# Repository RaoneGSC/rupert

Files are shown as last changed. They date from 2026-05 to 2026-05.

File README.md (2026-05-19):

# Rupert

<p align="center">
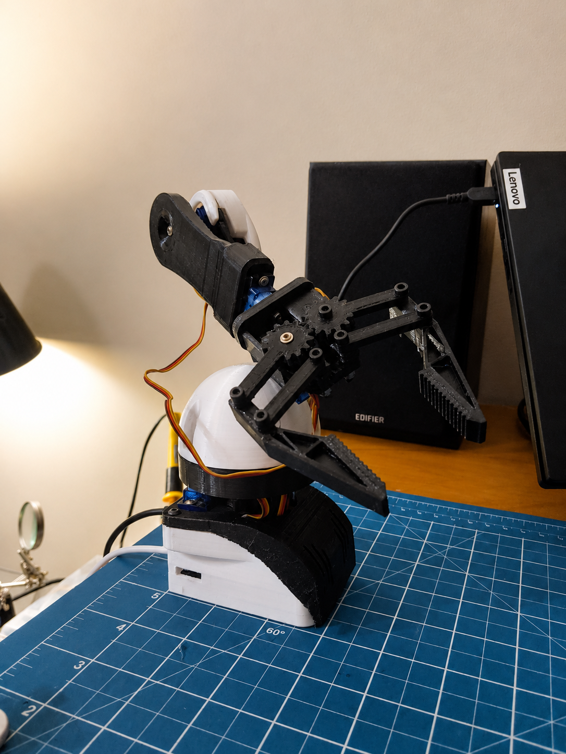
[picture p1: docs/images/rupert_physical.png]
Rupert robotic arm
  
</p>

> **Work in progress.** Rupert is an actively developed platform — control models, simulation, and hardware are continuously being improved. Expect rough edges.

Rupert is a 5-DOF robotic arm built from 3D-printed parts and off-the-shelf components, designed as a low-cost Physical AI testbed. It is the first robot of the [AxisMov](https://github.com/RaoneGSC/axismov) platform.

The main interest of the project is the **sim-to-real pipeline**: training or controlling the robot in simulation (NVIDIA Isaac Sim) and transferring that directly to the physical hardware via serial communication.

---

## Architecture

Rupert is split into two layers:

- **Brain** (`src/brain/`) — runs on the PC, handles simulation, AI, and high-level control
- **Firmware** (`firmware/`) — runs on the Raspberry Pi Pico 2, drives the servos directly

```
PC (Brain)  ──── USB Serial (230400 baud) ────  Pico 2 (Firmware)  ──── PWM ────  Servos
```

<p align="center">
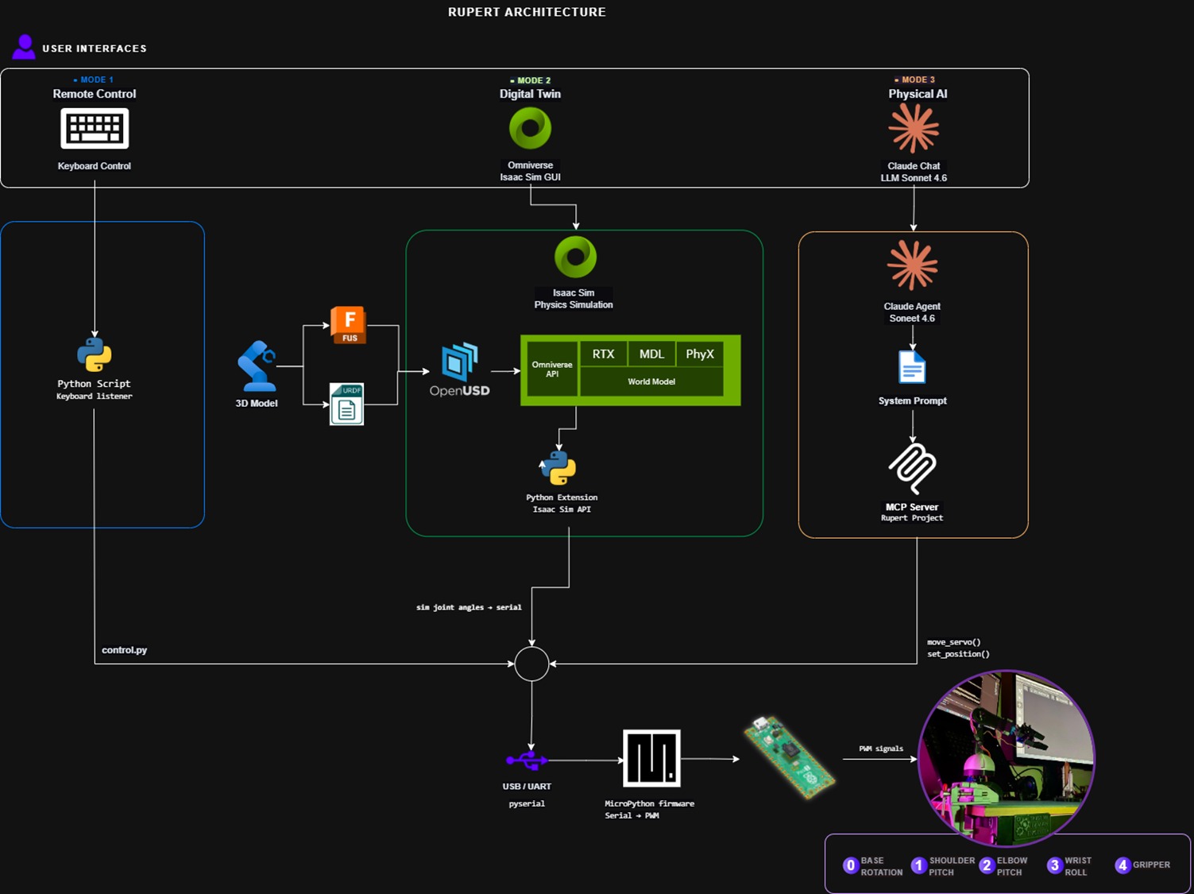
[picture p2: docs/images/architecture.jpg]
Rupert Architecture Diagram
  
</p>

---

## Firmware — Peripheral Nervous System

`firmware/peripheral_system.py` is the MicroPython script that runs on the **Raspberry Pi Pico 2**. Flash it using [Thonny](https://thonny.org/) or `mpremote`.

It listens on USB serial for commands in the format:

```
angle0,angle1,angle2,angle3,angle4\n
```

And responds with:

```
OK,angle0,angle1,angle2,angle3,angle4
```

Or `ERR,FORMAT` / `ERR,<message>` on failure. On startup it prints `READY`.

| Pin | Joint | Servo | Notes |
|---|---|---|---|
| 15 | Base | SG92R | carbon fiber gears — handles higher torque |
| 14 | Shoulder | MG90S | metal gear — highest load area |
| 13 | Elbow | SG92R | carbon fiber gears — handles higher torque |
| 12 | Wrist | SG90 | opens/closes gripper |
| 19 | Gripper | SG90 | wrist rotation |

---

## Kinematics

Rupert is a **5-DOF serial manipulator** with the following joint chain:

| Joint | Index | Motion | Range | Servo |
|---|---|---|---|---|
| Base | 0 | Rotation (yaw) | 5° – 175° | SG92R |
| Shoulder | 1 | Pitch | 5° – 160° | MG90S |
| Elbow | 2 | Pitch | 5° – 175° | SG92R |
| Wrist | 3 | Roll | 0° – 180° | SG90 |
| Gripper | 4 | Open / Close | 0° – 180° | SG90 |

**Kinematic chain:**

```
World → Base (yaw) → Shoulder (pitch) → Elbow (pitch) → Wrist (roll) → Gripper (end-effector)
```

- **Base** rotates the entire arm horizontally around the Z axis (yaw)
- **Shoulder + Elbow** form a planar 2-DOF arm in the vertical plane, controlling reach and height via two pitch joints
- **Wrist** rolls the gripper assembly around the forearm axis, allowing orientation of the end-effector
- **Gripper** is a parallel jaw mechanism actuated by a single servo

The arm operates in a **polar coordinate workspace** — the base angle sets the azimuth, while shoulder and elbow angles define the position in the vertical plane. No inverse kinematics solver is currently implemented; control is done by direct joint angle commands.

---

## Brain Modules

Rupert has multiple control interfaces, each in `src/brain/`:

| File | Description |
|---|---|
| `IsaacRupertBrain.py` | **Main sim-to-real bridge** — reads joint positions from Isaac Sim and streams them to the Pico via serial |
| `IsaacBridgeScript.py` | **Isaac Sim TCP bridge** — paste into Isaac Script Editor; opens a socket on port 9877 so the MCP can control the simulation thread-safely |
| `RupertBrainV3.py` | Keyboard-based direct control of the physical robot |
| `RupertBrainPyBulletV2.py` | PyBullet simulation + serial bridge ⚠️ partial assembly (2-DOF only) |
| `RupertBrainPyBulletV1.py` | First PyBullet prototype ⚠️ partial assembly |
| `RupertPhysicalAI.py` | Natural language control via LangChain + Groq |

> ⚠️ The PyBullet scripts and RL training environment (`src/training/`) model a **partial, 2-DOF version** of Rupert, not the full 5-DOF assembly. Full-assembly RL training is on the roadmap.

---

## MCP Servers

Rupert exposes three [MCP](https://modelcontextprotocol.io/) servers that let Claude Desktop control the robot directly:

| File | Server name | Description |
|---|---|---|
| `src/mcp/RupertMCP.py` | `rupert` | Serial servo control — `move_servo`, `move_sequence`, `center_all`, `current_position` |
| `src/mcp/RupertVisionMCP.py` | `rupert-vision` | Webcam computer vision — captures frames Claude can see, monitors motion, detects Rupert position via blue mat anchor |
| `src/mcp/IsaacUSDMCP.py` | `isaac-usd` | Isaac Sim control — connects to `IsaacBridgeScript.py` running inside Isaac, exposes scene inspection and drive control |

### Claude Code slash commands

Three project-scoped commands live in `.claude/commands/`:

| Command | Description |
|---|---|
| `/rupert-mover <text>` | Interprets a natural-language movement command and executes it via the `rupert` MCP |
| `/rupert-visao [goal]` | Full vision-action loop: starts webcam, moves arm, waits for motion to stop, checks result visually, fine-tunes |
| `/rupert-calibrar` | Runs each servo through its full range with camera feedback, reports OK / problem per joint |

---

## Sim-to-Real with NVIDIA Isaac Sim

The most developed pipeline uses **Isaac Sim** as the simulation environment. The robot is controlled in simulation and commands are streamed to the physical hardware in real time.

**Requirements:** [NVIDIA Isaac Sim](https://developer.nvidia.com/isaac/sim) (6.0+)

### Step 1 — Open the scene

Launch Isaac Sim, go to **File → Open**, navigate to the `assets/usd/` folder and open `IsaacRupert.usd`.

<p align="center">
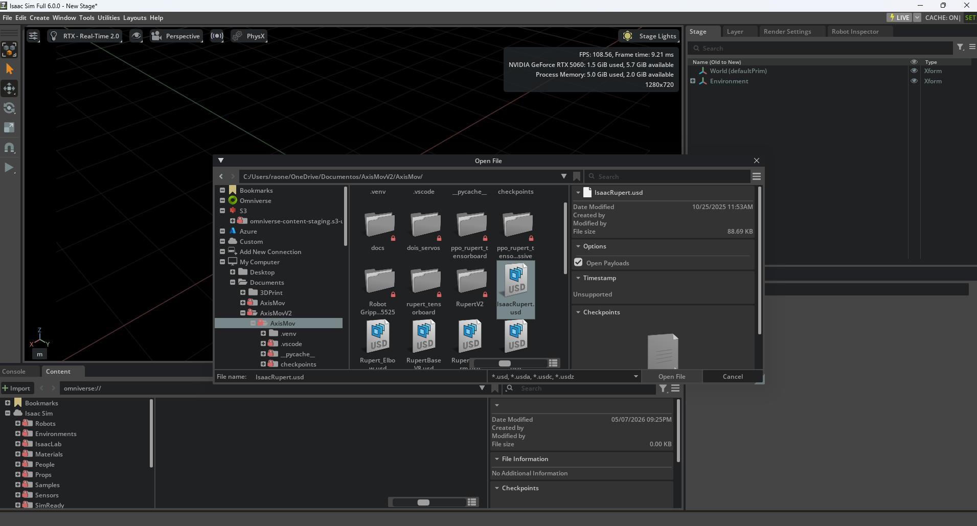
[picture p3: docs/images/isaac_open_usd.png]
Opening IsaacRupert.usd in Isaac Sim
  
</p>

### Step 2 — Flash the firmware

Flash `firmware/pico_servo_protected.py` to the Raspberry Pi Pico 2 using Thonny or `mpremote`. Connect the Pico via USB and confirm the COM port in `IsaacRupertBrain.py`.

### Step 3 — Run the brain script

Once the scene loads you should see Rupert in the viewport with all joints visible in the Physics Inspector.

<p align="center">
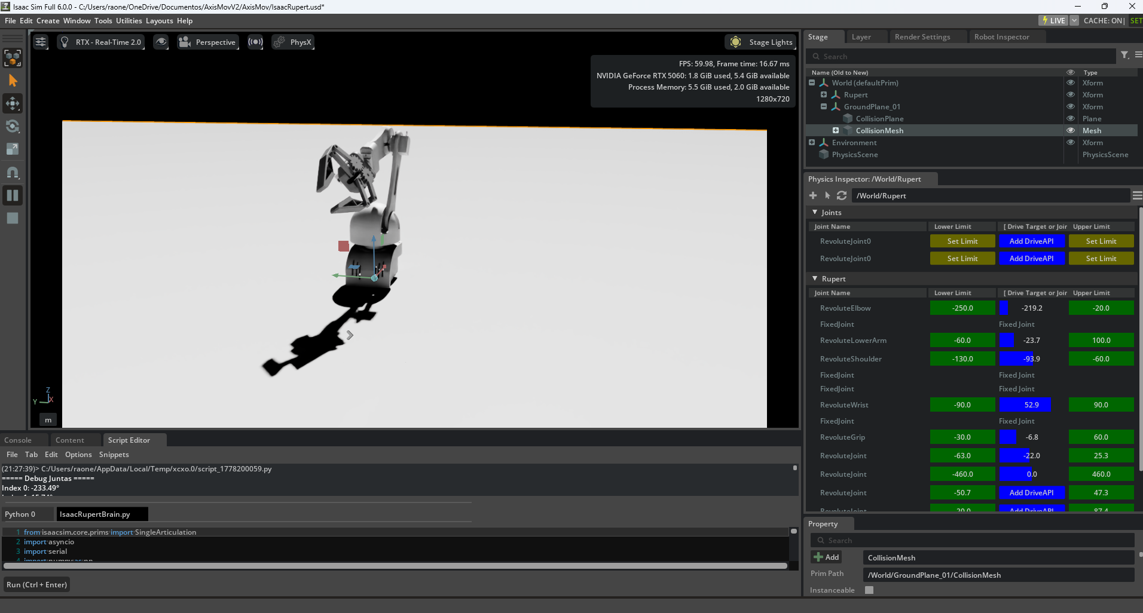
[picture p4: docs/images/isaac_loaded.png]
Rupert loaded in Isaac Sim with joints inspector
  
</p>

Open the **Script Editor** (bottom panel), load `src/brain/IsaacRupertBrain.py` and hit **Run (Ctrl+Enter)**.

The script will:
1. Connect to the Pico via serial (`COM4`, 230400 baud)
2. Start a smooth ramp from 90° to the current simulation position
3. Stream joint angles to the robot at 50Hz

### Step 4 (optional) — Enable Claude control via MCP

To let Claude Desktop control the simulation directly, also run `src/brain/IsaacBridgeScript.py` in the Script Editor. It opens a TCP socket on `localhost:9877` and exposes a thread-safe command queue so the `isaac-usd` MCP can inspect the scene and set drive targets without touching Isaac's USD APIs from the wrong thread.

Available bridge commands: `resumo`, `listar_prims`, `inspecionar`, `obter_juntas`, `buscar_prims`, `definir_drive`, `resetar_drives`, `articulacoes`.

---

## Computer Vision

Rupert uses a low-cost USB webcam as a visual sensor. Two components handle this:

- **`src/mcp/RupertVisionMCP.py`** — MCP server that returns `ImageContent` frames so Claude can see the robot directly. Supports continuous background monitoring, motion detection (frame-diff), and position detection.
- **`scripts/teste_visao_rupert.py`** — Standalone real-time test window (OpenCV). Run this to tune detection before using the MCP. Keyboard shortcuts: `O`=YOLO, `A`=ArUco, `M`=motion mask, `C`=debug masks, `S`=screenshot, `Q`=quit.

### Detection strategy

The robot sits on a **blue cutting mat** which acts as a position anchor:

1. Detect the blue-green mat via HSV segmentation (`H 78–115`)
2. Project the robot bounding-box above the mat
3. Confirm with SG90 servo blobs in the ROI (`H 95–140`)

If detection fails, use `calibrar_deteccao()` via the MCP (or press `C` in the test script) to see the HSV masks, then adjust thresholds with `ajustar_hsv_tapete()` at runtime.

---

## Hardware

Rupert is fully 3D-printable. All parts use **M3 screws**. STL and USD files are in `assets/`.

| Component | Details |
|---|---|
| Microcontroller | Raspberry Pi Pico 2 |
| Motor driver | [Kitronik Simply Robotics Motor Driver Board for Raspberry Pi Pico](https://kitronik.co.uk/products/5348-kitronik-simply-robotics-for-raspberry-pi-pico) |
| Base servo (pin 15) | SG92R — carbon fiber gears |
| Shoulder servo (pin 14) | MG90S — metal gear, highest load area |
| Elbow servo (pin 13) | SG92R — carbon fiber gears |
| Wrist servo (pin 12) | SG90 |
| Gripper servo (pin 19) | SG90 |
| Communication | USB Serial, 230400 baud |
| Fasteners | M3 screws |

---

## Known Issues

Rupert is a work in progress. These are the known limitations currently being addressed:

### Physical

- **Shoulder / Elbow torque** — Even with MG996R servos, the arm length generates more torque than the servos can handle. Movements in these joints are unreliable under load. Planned fix: shorten arm and forearm to reduce required torque.

- **Gripper grip strength** — The current gripper design does not hold objects reliably. For testing, use very lightweight objects (paper, foam). A redesigned gripper with better mechanical advantage is planned.

### Software / Simulation

- **Isaac Sim gripper joints** — The gripper joint connections in `IsaacRupert.usd` have structural issues that can crash the simulation depending on the movement. Needs a clean USD rebuild of the gripper assembly.

- **Ground constraint artifact** — The base is fixed to the ground plane to prevent tipping, which creates unnatural behavior in some poses. A proper base mass/inertia model is the correct fix.

- **PyBullet / RL is 2-DOF only** — The training environment and PyBullet scripts model a simplified 2-joint version of Rupert. Full 5-DOF RL environment is planned.

---

## Roadmap

- [x] **Isaac Sim MCP** — `IsaacUSDMCP.py` + `IsaacBridgeScript.py`: Claude can inspect the scene, read joints, and set drive targets directly from Claude Desktop
- [x] **Computer vision module** — `RupertVisionMCP.py`: webcam integration with blue-mat anchor detection, motion sensing, and `ImageContent` frames Claude can see natively; `scripts/teste_visao_rupert.py` for threshold tuning
- [ ] **Full 5-DOF RL environment** — Extend the Gymnasium environment to the complete arm assembly
- [ ] **Shorter arm/forearm** — Redesign to reduce torque on shoulder and elbow joints
- [ ] **Gripper redesign** — Better mechanical advantage for reliable grasping

---

## Setup

```bash
git clone https://github.com/RaoneGSC/rupert.git
cd rupert
pip install -r requirements.txt
cp .env.example .env   # add your API keys if using RupertPhysicalAI or Autogen
```

Flash the firmware to the Pico separately via Thonny or `mpremote copy firmware/peripheral_system.py :main.py`.

---

## License

MIT

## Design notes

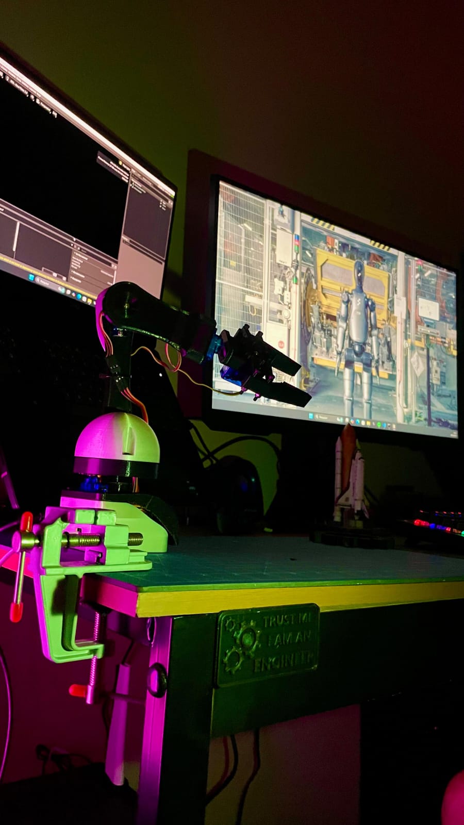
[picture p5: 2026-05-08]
docs/images/rupert_physical.jpg

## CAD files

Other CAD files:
assets/meshes/RupertHand6.stl
assets/meshes/RupertGrip2.stl
assets/meshes/RupertLowerArmV2.stl
assets/meshes/RupertHandTHEONE.stl
assets/meshes/Connector.stl
assets/meshes/RuportGrip1.stl
assets/meshes/RupertHand3.stl
assets/meshes/RupertHand4.stl
assets/meshes/RupertHand2.3.stl
assets/meshes/RupertHand2.stl
assets/meshes/RupertElbow.stl
assets/meshes/RupertHand2.1.stl
assets/meshes/RupertHand1.2.stl
assets/meshes/SG92R.stl
assets/meshes/RupertHand1.stl
assets/meshes/RupertHand7.stl
assets/meshes/RupertBaseV8.stl
assets/meshes/RupertShoulderV6.stl
assets/meshes/RupertForearm.stl
assets/meshes/RupertHand5.stl
assets/meshes/Rupert_Elbow.stl
assets/meshes/vader_saber.stl

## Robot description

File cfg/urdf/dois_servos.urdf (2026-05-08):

<?xml version="1.0"?>
<robot name="dois_servos">

  <!-- Servo Motor 1 (fixado na mesa) -->
  <link name="base_servo1">
    <visual>
      <geometry>
        <box size="0.032 0.012 0.026"/> <!-- Tamanho do servo motor 1 -->
      </geometry>
      <material name="gray"/>
    </visual>
    <collision>
      <geometry>
        <box size="0.032 0.012 0.026"/> <!-- Colisão do servo motor 1 -->
      </geometry>
    </collision>
    <inertial>
      <mass value="0.1"/> <!-- Massa padrão do servo motor 1 -->
      <inertia ix="0.0001" iy="0.0001" iz="0.0001"/> <!-- Inércia padrão -->
    </inertial>
  </link>

  <!-- Servo Motor 2 (girando com o primeiro) -->
  <link name="base_servo2">
    <visual>
      <geometry>
        <box size="0.032 0.012 0.026"/> <!-- Tamanho do servo motor 2 -->
      </geometry>
      <material name="blue"/>
    </visual>
    <collision>
      <geometry>
        <box size="0.032 0.012 0.026"/> <!-- Colisão do servo motor 2 -->
      </geometry>
    </collision>
    <inertial>
      <mass value="0.1"/> <!-- Massa padrão do servo motor 2 -->
      <inertia ix="0.0001" iy="0.0001" iz="0.0001"/> <!-- Inércia padrão -->
    </inertial>
  </link>

  <!-- Junta entre os dois servos (revoluta) -->
  <joint name="servo_joint" type="revolute">
    <parent link="base_servo1"/>
    <child link="base_servo2"/>
    <origin xyz="0 0 0.026"/> <!-- Posição do eixo de rotação -->
    <axis xyz="0 1 0"/> <!-- Eixo de rotação no eixo Y -->
    <limit lower="0" upper="3.14" effort="1" velocity="1"/> <!-- Limites da junta -->
  </joint>

  <!-- Chave Allen (visual, cilindro) -->
  <link name="chave_allen">
    <visual>
      <geometry>
        <cylinder radius="0.002" length="0.01"/> <!-- Representação visual da chave Allen -->
      </geometry>
      <material name="black"/>
    </visual>
    <collision>
      <geometry>
        <cylinder radius="0.002" length="0.01"/> <!-- Colisão da chave Allen -->
      </geometry>
    </collision>
    <inertial>
      <mass value="0.01"/> <!-- Massa pequena da chave Allen -->
      <inertia ix="0.00001" iy="0.00001" iz="0.00001"/> <!-- Inércia da chave Allen -->
    </inertial>
  </link>

  <!-- Junta entre o servo motor 2 e a chave Allen -->
  <joint name="chave_joint" type="revolute">
    <parent link="base_servo2"/>
    <child link="chave_allen"/>
    <origin xyz="0 0 0.013"/> <!-- Posição da chave Allen no eixo do servo motor 2 -->
    <axis xyz="0 1 0"/> <!-- Eixo de rotação da chave Allen -->
    <limit lower="0" upper="3.14" effort="1" velocity="1"/> <!-- Limites da junta -->
  </joint>

</robot>

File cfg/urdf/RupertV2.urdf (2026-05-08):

<robot name="RupertV2">
  <!-- ===================== RupertBase - RupertShoulder ==============================================-->
<!-- RupertBase -->
<link name="RupertBase">
  <!-- Aparência -->
  <visual>
    <origin xyz="0.1 0 -0.1" rpy="0 0 0"/>
    <geometry>
      <mesh filename="RupertBaseV8.stl" scale="0.01 0.01 0.01"/>
    </geometry>
    <material name="Preto Claro">
        <color rgba="0.2 0.2 0.2 1"/>
    </material>  
  </visual>
  <collision>
    <origin xyz="0 0 0.15" rpy="0 0 0"/>
    <geometry>
      <box size="0.7 0.6 0.4"/>
    </geometry>
  </collision>
  <inertial>
    <origin xyz="0 0 0" rpy="0 0 0" />
    <mass value="1" />
    <inertia ixx="0.000034533333" ixy="0" ixz="0" iyx="0" iyy="0.000034533333" iyz="0" izx="0" izy="0" izz="0.0000648" />
  </inertial>
</link>

<!-- RupertShoulder -->
<link name="RupertShoulder">
  <!-- Aparência -->
  <visual>
    <origin xyz="0 0 -0.05" rpy="0 0 4.71"/>
    <geometry>
      <mesh filename="RupertShoulderV6.stl" scale="0.01 0.01 0.01"/>
    </geometry>
    <material name="Branco">
        <color rgba="0.9 0.9 0.9 0.99"/>
    </material>  
  </visual>
  <collision>
    <origin xyz="-0,1 0 0.1" rpy="0 0 0"/>
    <geometry>
      <box size="0.4 0.4 0.5"/>
    </geometry>
  </collision>
  <inertial>
    <origin xyz="0 0 0" rpy="0 0 0" />
    <mass value="0.1" />
    <inertia ixx="0.000034533333" ixy="0" ixz="0" iyx="0" iyy="0.000034533333" iyz="0" izx="0" izy="0" izz="0.0000648" />
  </inertial>
</link>

<!-- joint1 (rotação no eixo Z) -->
<joint name="joint1" type="revolute">
  <!-- link pai -->
  <parent link="RupertBase"/>
  <!-- link filho -->
  <child link="RupertShoulder"/>
  
  <!-- Origem da junta (posicionando para que o RupertShoulder gire em torno da RupertBase) -->
  <origin xyz="0.05 0 0.5" rpy="0 0 0"/>
  
  <!-- Eixo de rotação: rotação no eixo Z para giro no plano XY -->
  <axis xyz="0 0 1"/>
  
  <!-- Limitações de rotação -->
  <limit effort="100" lower="-0.5" upper="0.5" velocity="1.0"/>
</joint>

  <!-- ================================================================================== -->

  <!-- ===================== RupertShoulder - RupertLowerArm ==============================================-->
  <!-- RupertLowerArm -->
  <link name="RupertLowerArm">
    <visual>
      <origin xyz="0.0 0.19 0" rpy="1.57 3.14 0"/>
      <geometry>
        <mesh filename="RupertLowerArmV2.stl" scale="0.01 0.01 0.01"/>
      </geometry>
      <material name="Preto Claro">
        <color rgba="0.2 0.2 0.2 1"/>
      </material>   
    </visual>

    <collision>
      <origin xyz="0 0.19 0.6" rpy="0 0 0"/>
      <geometry>
        <box size="0.2 0.05 1.1"/>
      </geometry>
    </collision>

    <inertial>
        <origin xyz="0 0 0" rpy="0 0 0" />
        <mass value="0.1" />
        <inertia ixx="0.000034533333" ixy="0" ixz="0" iyx="0" iyy="0.000034533333" iyz="0" izx="0" izy="0" izz="0.0000648" />
    </inertial>
  </link>

  <!-- joint2 （Revolução no plano xy） -->
  <joint name="joint2" type="revolute">
    <parent link="RupertShoulder"/>
    <child link="RupertLowerArm"/>
    <origin xyz="0 0 0.2" rpy="0 0 0"/>
    <axis xyz="0 1 0"/>
    <limit effort="100" velocity="1" lower="-1.57" upper="1.57"/> <!-- 0 a 180 graus -->
  </joint>
  
  

 

</robot>

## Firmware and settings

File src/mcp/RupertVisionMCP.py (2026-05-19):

#!/usr/bin/env python3
# RupertVisionMCP.py — Servidor MCP de visão para monitorar o Rupert via webcam
import base64
import io
import sys
import threading
import time
from datetime import datetime
from typing import Optional

import cv2
import mcp.types as mcp_types
import numpy as np
from PIL import Image
from mcp.server.fastmcp import FastMCP

mcp = FastMCP("rupert-vision")

# ─── Estado global ─────────────────────────────────────────────────────────────
_camera: Optional[cv2.VideoCapture] = None
_camera_index: int = 0
_ultimo_frame: Optional[np.ndarray] = None
_monitorando: bool = False
_thread_monitor: Optional[threading.Thread] = None
_historico_movimento: list[float] = []
_total_frames: int = 0
_lock = threading.Lock()


# ─── Helpers internos ──────────────────────────────────────────────────────────
def _abrir_camera(index: int = 0) -> cv2.VideoCapture:
    global _camera, _camera_index
    if _camera is not None and _camera.isOpened() and _camera_index == index:
        return _camera
    if _camera is not None:
        _camera.release()
    cam = cv2.VideoCapture(index, cv2.CAP_DSHOW)
    if not cam.isOpened():
        cam = cv2.VideoCapture(index)
    if not cam.isOpened():
        raise RuntimeError(f"Não foi possível abrir câmera {index}")
    cam.set(cv2.CAP_PROP_FRAME_WIDTH, 640)
    cam.set(cv2.CAP_PROP_FRAME_HEIGHT, 480)
    _camera = cam
    _camera_index = index
    return cam


def _frame_para_base64(frame: np.ndarray, qualidade: int = 80) -> str:
    rgb = cv2.cvtColor(frame, cv2.COLOR_BGR2RGB)
    img = Image.fromarray(rgb)
    buf = io.BytesIO()
    img.save(buf, format="JPEG", quality=qualidade)
    return base64.b64encode(buf.getvalue()).decode()


def _diferenca_percentual(a: np.ndarray, b: np.ndarray) -> float:
    """Retorna % de pixels que mudaram mais de 15 pontos entre dois frames."""
    diff = cv2.absdiff(cv2.cvtColor(a, cv2.COLOR_BGR2GRAY),
                       cv2.cvtColor(b, cv2.COLOR_BGR2GRAY))
    changed = np.sum(diff > 15)
    return 100.0 * changed / diff.size


def _loop_monitoramento(intervalo_s: float, camera_index: int):
    global _ultimo_frame, _monitorando, _historico_movimento, _total_frames
    try:
        cam = _abrir_camera(camera_index)
        frame_anterior = None
        while _monitorando:
            ok, frame = cam.read()
            if not ok:
                time.sleep(intervalo_s)
                continue
            with _lock:
                _ultimo_frame = frame.copy()
                _total_frames += 1
                if frame_anterior is not None:
                    diff = _diferenca_percentual(frame_anterior, frame)
                    _historico_movimento.append(diff)
                frame_anterior = frame.copy()
            time.sleep(intervalo_s)
    except Exception as e:
        print(f"[rupert-vision] Erro no monitoramento: {e}", file=sys.stderr)
    finally:
        _monitorando = False


# ─── Tools MCP ─────────────────────────────────────────────────────────────────
@mcp.tool()
def capturar_frame(
    camera_index: int = 0, qualidade: int = 80
) -> list[mcp_types.TextContent | mcp_types.ImageContent]:
    """Captura um frame da webcam e envia a foto para Claude ver o Rupert.

    Retorna tanto a imagem visual (Claude pode ver diretamente) quanto
    metadados de texto com dimensões e timestamp.

    Args:
        camera_index: índice da câmera (0 = câmera padrão)
        qualidade: qualidade JPEG 1-100 (padrão 80)
    """
    try:
        cam = _abrir_camera(camera_index)
        # descarta 3 frames para a câmera ajustar exposição
        for _ in range(3):
            cam.read()
        ok, frame = cam.read()
        if not ok:
            return [mcp_types.TextContent(type="text", text="Erro: não foi possível capturar frame da câmera")]
        with _lock:
            global _ultimo_frame
            _ultimo_frame = frame.copy()
        h, w = frame.shape[:2]
        ts = datetime.now().strftime("%H:%M:%S")
        b64 = _frame_para_base64(frame, qualidade)
        return [
            mcp_types.TextContent(type="text", text=f"Foto capturada — {w}x{h}px | {ts}"),
            mcp_types.ImageContent(type="image", data=b64, mimeType="image/jpeg"),
        ]
    except Exception as e:
        return [mcp_types.TextContent(type="text", text=f"Erro ao capturar frame: {e}")]


@mcp.tool()
def iniciar_monitoramento(intervalo_s: float = 1.0, camera_index: int = 0) -> str:
    """Inicia monitoramento contínuo da webcam em background.

    Captura frames em loop com o intervalo especificado. Use obter_frame_atual()
    para buscar o frame mais recente sem latência de abertura de câmera.
    Use aguardar_movimento_parar() para detectar quando o Rupert parou de se mover.

    Args:
        intervalo_s: intervalo entre capturas em segundos (padrão 1.0)
        camera_index: índice da câmera (0 = câmera padrão)
    """
    global _monitorando, _thread_monitor, _historico_movimento, _total_frames

    if _monitorando:
        return "Monitoramento já está em execução. Use parar_monitoramento() primeiro."

    _historico_movimento.clear()
    _total_frames = 0
    _monitorando = True

    _thread_monitor = threading.Thread(
        target=_loop_monitoramento,
        args=(intervalo_s, camera_index),
        daemon=True,
    )
    _thread_monitor.start()
    time.sleep(0.5)  # deixa a thread abrir a câmera

    if _monitorando:
        return (
            f"Monitoramento iniciado. Capturando a cada {intervalo_s}s. "
            f"Use obter_frame_atual() para ver o Rupert, "
            f"ou aguardar_movimento_parar() para esperar ele parar."
        )
    return "Erro ao iniciar monitoramento — verifique se a câmera está disponível."


@mcp.tool()
def parar_monitoramento() -> str:
    """Para o monitoramento contínuo da webcam e retorna estatísticas.

    Returns:
        Resumo com total de frames capturados e média de movimento detectado.
    """
    global _monitorando, _camera

    if not _monitorando:
        return "Monitoramento não está em execução."

    _monitorando = False
    if _thread_monitor is not None:
        _thread_monitor.join(timeout=3.0)

    total = _total_frames
    media_mov = (
        sum(_historico_movimento) / len(_historico_movimento)
        if _historico_movimento
        else 0.0
    )

    if _camera is not None:
        _camera.release()
        _camera = None

    return (
        f"Monitoramento parado. "
        f"Total de frames: {total} | "
        f"Movimento médio detectado: {media_mov:.2f}% de pixels alterados."
    )


@mcp.tool()
def obter_frame_atual(
    qualidade: int = 80,
) -> list[mcp_types.TextContent | mcp_types.ImageContent]:
    """Retorna a foto mais recente capturada pelo monitoramento.

    Mais rápido que capturar_frame() pois não abre a câmera de novo.
    Requer que iniciar_monitoramento() tenha sido chamado antes.

    Args:
        qualidade: qualidade JPEG 1-100 (padrão 80)
    """
    with _lock:
        frame = _ultimo_frame.copy() if _ultimo_frame is not None else None

    if frame is None:
        return [mcp_types.TextContent(
            type="text",
            text="Nenhum frame disponível. Chame iniciar_monitoramento() ou capturar_frame() primeiro.",
        )]

    h, w = frame.shape[:2]
    ts = datetime.now().strftime("%H:%M:%S")
    mov = _historico_movimento[-1] if _historico_movimento else None
    info = f"Frame atual — {w}x{h}px | {ts}"
    if mov is not None:
        info += f" | Movimento recente: {mov:.1f}%"
    return [
        mcp_types.TextContent(type="text", text=info),
        mcp_types.ImageContent(type="image", data=_frame_para_base64(frame, qualidade), mimeType="image/jpeg"),
    ]


@mcp.tool()
def aguardar_movimento_parar(
    timeout_s: float = 8.0, limiar_pixels: float = 2.0
) -> list[mcp_types.TextContent | mcp_types.ImageContent]:
    """Aguarda até que o Rupert pare de se mover (frames estabilizem).

    Bloqueia até que a diferença entre frames consecutivos caia abaixo de
    limiar_pixels% — sinaliza que o servo chegou na posição final.
    Requer que iniciar_monitoramento() esteja ativo.

    Use no loop de feedback visual:
      1. mover_servo() via MCP rupert
      2. aguardar_movimento_parar()  ← espera o servo chegar
      3. obter_frame_atual()         ← vê resultado
      4. Analisa e corrige se necessário

    Args:
        timeout_s: tempo máximo de espera em segundos (padrão 8.0)
        limiar_pixels: % mínima de pixels alterados para considerar "parado" (padrão 2.0)

    Returns:
        dict com parou (bool), tempo_decorrido (float) e frame_final_base64 (str)
    """
    if not _monitorando:
        return [mcp_types.TextContent(
            type="text",
            text="Erro: monitoramento não está ativo. Chame iniciar_monitoramento() primeiro.",
        )]

    inicio = time.time()
    estavel_count = 0  # quantas leituras consecutivas abaixo do limiar

    while time.time() - inicio < timeout_s:
        time.sleep(0.2)
        if len(_historico_movimento) >= 2:
            ultima_diff = _historico_movimento[-1]
            if ultima_diff < limiar_pixels:
                estavel_count += 1
                if estavel_count >= 3:  # 3 leituras estáveis consecutivas
                    break
            else:
                estavel_count = 0

    decorrido = time.time() - inicio
    parou = estavel_count >= 3

    with _lock:
        frame = _ultimo_frame.copy() if _ultimo_frame is not None else None

    mov_final = _historico_movimento[-1] if _historico_movimento else None
    status = "PAROU" if parou else f"TIMEOUT após {timeout_s}s"
    info = (
        f"{status} | Tempo: {round(decorrido, 2)}s | "
        f"Movimento final: {mov_final:.1f}%" if mov_final is not None
        else f"{status} | Tempo: {round(decorrido, 2)}s"
    )
    if not parou:
        info += " | Rupert pode ainda estar em movimento ou limiar muito baixo."

    conteudo: list[mcp_types.TextContent | mcp_types.ImageContent] = [
        mcp_types.TextContent(type="text", text=info)
    ]
    if frame is not None:
        conteudo.append(
            mcp_types.ImageContent(type="image", data=_frame_para_base64(frame), mimeType="image/jpeg")
        )
    return conteudo


# ─── Detecção do Rupert (tapete azul como âncora) ─────────────────────────────
_tapete_hsv_lo = np.array([ 78,  50,  30])
_tapete_hsv_hi = np.array([115, 255, 200])
_servo_hsv_lo  = np.array([ 95,  70,  50])
_servo_hsv_hi  = np.array([140, 255, 220])
_TAPETE_AREA_MIN = 4000
_SERVO_BLOB_MIN  = 40
_SERVO_BLOB_MAX  = 1800


def _detectar_rupert(frame: np.ndarray) -> dict | None:
    h, w = frame.shape[:2]
    hsv  = cv2.cvtColor(frame, cv2.COLOR_BGR2HSV)

    mask_tap = cv2.inRange(hsv, _tapete_hsv_lo, _tapete_hsv_hi)
    mask_tap = cv2.morphologyEx(mask_tap, cv2.MORPH_OPEN,  np.ones((5,  5),  np.uint8))
    mask_tap = cv2.morphologyEx(mask_tap, cv2.MORPH_CLOSE, np.ones((20, 20), np.uint8))

    cnts, _ = cv2.findContours(mask_tap, cv2.RETR_EXTERNAL, cv2.CHAIN_APPROX_SIMPLE)
    cnts    = [c for c in cnts if cv2.contourArea(c) >= _TAPETE_AREA_MIN]
    if not cnts:
        return None

    tapete        = max(cnts, key=cv2.contourArea)
    tx, ty, tw, th_t = cv2.boundingRect(tapete)
    area_tap      = cv2.contourArea(tapete)

    margem = max(tw, th_t)
    x1 = max(0, tx - 10)
    x2 = min(w, tx + tw + 10)
    y2 = min(h, ty + th_t // 4)
    y1 = max(0, ty - margem)

    roi_hsv   = hsv[y1:y2, x1:x2]
    mask_srv  = cv2.inRange(roi_hsv, _servo_hsv_lo, _servo_hsv_hi)
    mask_srv  = cv2.morphologyEx(mask_srv, cv2.MORPH_OPEN, np.ones((3, 3), np.uint8))
    cnts_s, _ = cv2.findContours(mask_srv, cv2.RETR_EXTERNAL, cv2.CHAIN_APPROX_SIMPLE)
    n_servo   = sum(1 for c in cnts_s
                    if _SERVO_BLOB_MIN <= cv2.contourArea(c) <= _SERVO_BLOB_MAX)

    mask_srv_full = np.zeros((h, w), np.uint8)
    mask_srv_full[y1:y2, x1:x2] = mask_srv

    return {
        "bbox":        (x1, y1, x2, y2),
        "tapete_bbox": (tx, ty, tw, th_t),
        "score":       area_tap / 1000.0 + n_servo * 5.0,
        "n_servo":     n_servo,
        "masks":       {"tapete": mask_tap, "servo": mask_srv_full},
    }


def _anotar_frame(frame: np.ndarray, r: dict) -> np.ndarray:
    out = frame.copy()
    x1, y1, x2, y2 = r["bbox"]
    tx, ty, tw, th_t = r["tapete_bbox"]
    cor = (0, 255, 80)
    L   = 22

    cv2.rectangle(out, (tx, ty), (tx + tw, ty + th_t), (0, 165, 255), 1)
    cv2.putText(out, "tapete", (tx + 4, ty + 14),
                cv2.FONT_HERSHEY_SIMPLEX, 0.38, (0, 165, 255), 1)

    for px, py, dx, dy in [(x1,y1,1,1),(x2,y1,-1,1),(x1,y2,1,-1),(x2,y2,-1,-1)]:
        cv2.line(out, (px, py), (px + dx*L, py), cor, 3)
        cv2.line(out, (px, py), (px, py + dy*L), cor, 3)

    lbl = f"Rupert  servos:{r['n_servo']}  score:{r['score']:.0f}"
    (tw_l, th_l), _ = cv2.getTextSize(lbl, cv2.FONT_HERSHEY_SIMPLEX, 0.5, 1)
    cv2.rectangle(out, (x1, y1 - th_l - 8), (x1 + tw_l + 6, y1), (0, 70, 0), -1)
    cv2.putText(out, lbl, (x1 + 3, y1 - 4),
                cv2.FONT_HERSHEY_SIMPLEX, 0.5, (180, 255, 180), 1)
    return out


@mcp.tool()
def detectar_posicao_rupert(
    camera_index: int = 0, qualidade: int = 80
) -> list[mcp_types.TextContent | mcp_types.ImageContent]:
    """Captura um frame e detecta a posição do Rupert usando o tapete azul como âncora.

    Pipeline:
      1. Detecta o tapete azul-esverdeado por HSV
      2. Projeta o bounding-box do Rupert acima do tapete
      3. Confirma com blobs dos servos SG90 azuis na ROI

    Retorna a foto anotada (bounding-box, tapete, score) + dados estruturados.
    Se não encontrar o tapete, retorna foto crua com aviso — use calibrar_deteccao()
    para ver as máscaras de cor e ajustar os limiares com ajustar_hsv_tapete().

    Args:
        camera_index: índice da câmera (0 = padrão)
        qualidade: qualidade JPEG 1-100
    """
    try:
        cam = _abrir_camera(camera_index)
        for _ in range(3):
            cam.read()
        ok, frame = cam.read()
        if not ok:
            return [mcp_types.TextContent(type="text", text="Erro: não foi possível capturar frame")]
        with _lock:
            global _ultimo_frame
            _ultimo_frame = frame.copy()

        r = _detectar_rupert(frame)
        ts = datetime.now().strftime("%H:%M:%S")

        if r is None:
            info = (
                f"[{ts}] Rupert NÃO detectado — tapete azul não encontrado na cena. "
                f"Limiares atuais: tapete H[{_tapete_hsv_lo[0]}-{_tapete_hsv_hi[0]}] "
                f"S[{_tapete_hsv_lo[1]}-{_tapete_hsv_hi[1]}] V[{_tapete_hsv_lo[2]}-{_tapete_hsv_hi[2]}]. "
                f"Use calibrar_deteccao() para ver as máscaras ou ajustar_hsv_tapete() para ajustar."
            )
            return [
                mcp_types.TextContent(type="text", text=info),
                mcp_types.ImageContent(type="image", data=_frame_para_base64(frame, qualidade), mimeType="image/jpeg"),
            ]

        x1, y1, x2, y2 = r["bbox"]
        info = (
            f"[{ts}] Rupert DETECTADO | "
            f"bbox: ({x1},{y1})→({x2},{y2}) | "
            f"score: {r['score']:.0f} | "
            f"servos visíveis: {r['n_servo']} | "
            f"tapete: {r['tapete_bbox']}"
        )
        anotado = _anotar_frame(frame, r)
        return [
            mcp_types.TextContent(type="text", text=info),
            mcp_types.ImageContent(type="image", data=_frame_para_base64(anotado, qualidade), mimeType="image/jpeg"),
        ]
    except Exception as e:
        return [mcp_types.TextContent(type="text", text=f"Erro na detecção: {e}")]


@mcp.tool()
def calibrar_deteccao(
    camera_index: int = 0,
) -> list[mcp_types.TextContent | mcp_types.ImageContent]:
    """Captura um frame e mostra as máscaras de cor usadas na detecção.

    Retorna dois painéis lado a lado:
      - Esquerda: máscara do tapete azul (laranja = detectado)
      - Direita:  máscara dos servos SG90 (azul = detectado)

    Use para diagnosticar por que o Rupert não está sendo detectado e
    para calibrar os limiares HSV com ajustar_hsv_tapete().

    Args:
        camera_index: índice da câmera (0 = padrão)
    """
    try:
        cam = _abrir_camera(camera_index)
        for _ in range(3):
            cam.read()
        ok, frame = cam.read()
        if not ok:
            return [mcp_types.TextContent(type="text", text="Erro: não foi possível capturar frame")]

        r = _detectar_rupert(frame)
        h, w = frame.shape[:2]

        def _colorir(mask: np.ndarray, cor_bgr: tuple, titulo: str) -> np.ndarray:
            img = np.zeros((h, w, 3), np.uint8)
            img[mask > 0] = cor_bgr
            # mostra contorno no frame original levemente
            frame_escuro = (frame * 0.3).astype(np.uint8)
            img = cv2.addWeighted(img, 0.7, frame_escuro, 0.3, 0)
            cv2.putText(img, titulo, (6, 20), cv2.FONT_HERSHEY_SIMPLEX, 0.55, (220, 220, 220), 1)
            return img

        vazio = np.zeros((h, w), np.uint8)
        masks = r["masks"] if r else {"tapete": vazio, "servo": vazio}

        vis_tap = _colorir(masks["tapete"], (0, 165, 255), "tapete (ancora)")
        vis_srv = _colorir(masks["servo"],  (255, 80,  20), "servos SG90")
        painel  = np.hstack([vis_tap, vis_srv])

        encontrou = "DETECTADO" if r else "NÃO DETECTADO"
        n_servo   = r["n_servo"] if r else 0
        info = (
            f"Calibração | Rupert: {encontrou} | servos visíveis: {n_servo} | "
            f"Tapete HSV H[{_tapete_hsv_lo[0]}-{_tapete_hsv_hi[0]}] "
            f"S[{_tapete_hsv_lo[1]}-{_tapete_hsv_hi[1]}] "
            f"V[{_tapete_hsv_lo[2]}-{_tapete_hsv_hi[2]}] | "
            f"Use ajustar_hsv_tapete() para modificar os limiares."
        )
        return [
            mcp_types.TextContent(type="text", text=info),
            mcp_types.ImageContent(type="image", data=_frame_para_base64(painel), mimeType="image/jpeg"),
        ]
    except Exception as e:
        return [mcp_types.TextContent(type="text", text=f"Erro na calibração: {e}")]


@mcp.tool()
def ajustar_hsv_tapete(
    h_lo: int, s_lo: int, v_lo: int,
    h_hi: int, s_hi: int, v_hi: int,
) -> str:
    """Ajusta os limiares HSV do tapete azul em runtime (sem reiniciar o MCP).

    Use após ver as máscaras com calibrar_deteccao() e identificar que o tapete
    não está sendo capturado corretamente.

    Referência HSV no OpenCV: H=0-179, S=0-255, V=0-255
    Tapete azul-esverdeado típico: H≈85-115, S≈50-255, V≈30-200

    Args:
        h_lo, s_lo, v_lo: limite inferior (Hue, Saturation, Value)
        h_hi, s_hi, v_hi: limite superior
    """
    global _tapete_hsv_lo, _tapete_hsv_hi
    _tapete_hsv_lo = np.array([h_lo, s_lo, v_lo])
    _tapete_hsv_hi = np.array([h_hi, s_hi, v_hi])
    return (
        f"Limiares HSV do tapete atualizados: "
        f"LO=[{h_lo},{s_lo},{v_lo}] HI=[{h_hi},{s_hi},{v_hi}]. "
        f"Chame calibrar_deteccao() para verificar o resultado."
    )


@mcp.tool()
def status_camera() -> dict:
    """Retorna o status atual da câmera e do monitoramento.

    Returns:
        dict com informações de câmera aberta, monitoramento ativo,
        total de frames, e movimento médio detectado.
    """
    return {
        "camera_aberta": _camera is not None and _camera.isOpened(),
        "monitorando": _monitorando,
        "total_frames_capturados": _total_frames,
        "movimento_medio_pct": (
            round(sum(_historico_movimento) / len(_historico_movimento), 2)
            if _historico_movimento
            else None
        ),
        "ultimo_movimento_pct": (
            _historico_movimento[-1] if _historico_movimento else None
        ),
    }


# ─── Inicialização ─────────────────────────────────────────────────────────────
if __name__ == "__main__":
    print("Rupert Vision MCP Server iniciando...", flush=True, file=sys.stderr)
    print(
        "Tools disponíveis: capturar_frame, iniciar_monitoramento, "
        "parar_monitoramento, obter_frame_atual, aguardar_movimento_parar, status_camera",
        flush=True,
        file=sys.stderr,
    )
    mcp.run()

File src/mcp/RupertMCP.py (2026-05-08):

#!/usr/bin/env python3
# RupertMCP.py — MCP server for controlling Rupert via Claude Desktop
import serial, time, sys
from typing import List, Dict, Any
from mcp.server.fastmcp import FastMCP

# ─── Serial ───────────────────────────────────────────────────────────────────
PORT = "COM4"
BAUD  = 230400
ser   = serial.Serial(PORT, BAUD, timeout=0.2)

# ─── State ────────────────────────────────────────────────────────────────────
angles = [90.0] * 5

# ─── Parameters ───────────────────────────────────────────────────────────────
STEP_BASE = [5.0,  2.0,  5.0,  5.0,  5.0]
DELAY     = 0.05
DEADBAND  = 1.0
ANGLE_MIN = [5,   5,   5,   0,   0]
ANGLE_MAX = [175, 160, 175, 180, 180]
SERVOS    = ["base", "shoulder", "elbow", "wrist", "gripper"]
GRIP_IDX         = 4    # gripper servo index
GRIP_HOLD_OFFSET = 10   # extra degrees to maintain grip pressure

# ─── Serial communication ──────────────────────────────────────────────────────
def send():
    cmd_angles = angles.copy()
    g = cmd_angles[GRIP_IDX]
    if abs(g - 90) > 5:  # outside neutral = gripping something
        direction = 1 if g > 90 else -1
        cmd_angles[GRIP_IDX] = max(ANGLE_MIN[GRIP_IDX], min(ANGLE_MAX[GRIP_IDX], g + direction * GRIP_HOLD_OFFSET))
    cmd = ",".join(str(int(round(a))) for a in cmd_angles) + "\n"
    ser.write(cmd.encode())
    try:
        resp = ser.readline().decode().strip()
        if resp:
            print(f"[Pico] {resp}", flush=True, file=sys.stderr)
    except Exception:
        pass

def move_to(idx: int, target: float):
    target = max(ANGLE_MIN[idx], min(ANGLE_MAX[idx], target))
    dist = abs(target - angles[idx])
    if dist <= DEADBAND:
        return
    angles[idx] = target
    send()
    # wait proportional to distance so servo has time to reach target
    time.sleep(max(0.4, dist * 0.025))

# ─── MCP Server ───────────────────────────────────────────────────────────────
mcp = FastMCP("Rupert")

@mcp.tool()
def move_servo(servo: str, angle: float) -> str:
    """Move a robot servo to the specified angle.

    Servos and correct directions:
      - base      : RIGHT=smaller angle (e.g. 45°)    LEFT=larger angle (e.g. 135°)   forward=90°
      - shoulder  : UP=larger angle (e.g. 130°)       DOWN=smaller angle (e.g. 45°)   horizontal=90°
      - elbow     : EXTEND=larger angle (e.g. 135°)   FOLD=smaller angle (e.g. 45°)   straight=90°
      - wrist     : OPEN gripper=0°                   CLOSE gripper=180°
      - gripper   : wrist/gripper rotation             neutral=90°

    Args:
        servo: servo name (base, shoulder, elbow, wrist or gripper)
        angle: target angle in degrees
    """
    servo = servo.lower().strip()
    if servo not in SERVOS:
        return f"Invalid servo '{servo}'. Use: {', '.join(SERVOS)}"
    idx  = SERVOS.index(servo)
    target = max(ANGLE_MIN[idx], min(ANGLE_MAX[idx], float(angle)))
    print(f"→ {servo} → {target:.0f}°", flush=True, file=sys.stderr)
    move_to(idx, target)
    return f"{servo} positioned at {angles[idx]:.0f}°"

@mcp.tool()
def current_position() -> str:
    """Returns the current position in degrees of all robot servos."""
    parts = [f"{SERVOS[i]}: {angles[i]:.0f}°" for i in range(5)]
    return "Current position → " + " | ".join(parts)

@mcp.tool()
def center_all() -> str:
    """Moves all servos to 90° (robot center/neutral position)."""
    print("→ Centering...", flush=True, file=sys.stderr)
    for i in range(5):
        move_to(i, 90.0)
    return "Robot centered at 90° on all axes."

@mcp.tool()
def move_sequence(movements: List[Dict[str, Any]]) -> str:
    """Executes a sequence of movements on multiple servos.

    Use for commands involving more than one servo at a time.

    Args:
        movements: list of objects {"servo": str, "angle": float}
                   Example: [{"servo": "shoulder", "angle": 130}, {"servo": "wrist", "angle": 0}]
    """
    results = []
    for m in movements:
        s = str(m.get("servo", "")).lower().strip()
        a = m.get("angle")
        if s in SERVOS and a is not None:
            idx    = SERVOS.index(s)
            target = max(ANGLE_MIN[idx], min(ANGLE_MAX[idx], float(a)))
            print(f"→ {s} → {target:.0f}°", flush=True, file=sys.stderr)
            move_to(idx, target)
            results.append(f"{s}={angles[idx]:.0f}°")
        else:
            results.append(f"skipped: {m}")
    return "Sequence done: " + ", ".join(results)

# ─── Entry point ───────────────────────────────────────────────────────────────
if __name__ == "__main__":
    print("Rupert MCP Server starting...", flush=True, file=sys.stderr)
    send()
    time.sleep(0.1)
    print("Ready. Waiting for Claude Desktop.", flush=True, file=sys.stderr)
    mcp.run()

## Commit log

2026-05-08 feat: initial Rupert robot project
    Braço robótico 5-DOF com Isaac Sim, PyBullet, PPO/RL, MCP server e comunicação serial com Raspberry Pi Pico.
    [Connector.stl, RupertBaseV8.stl, RupertElbow.stl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]
2026-05-08 docs: translate all content to English
    All comments, docstrings, print statements, error messages and user-facing
    strings translated from Portuguese to English across all source files.
    Servo names updated: ombro→shoulder, cotovelo→elbow, pulso→wrist, garra→gripper.
    [IsaacRupertBrain.py, RupertMCP.py, RupertPhysicalAI.py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]
2026-05-08 refactor: rename Teste_FullRupert to RupertBrainV3 and move to brain/
    Was misplaced in simulation/ — it is the most up-to-date brain/control script.
2026-05-08 docs: full README rewrite with hardware, sim-to-real guide and known issues
    - Add physical photo and Isaac Sim screenshots
    - Document step-by-step Isaac Sim sim-to-real pipeline
    - Add hardware table (RPi Pico 2, Kitronik board, MG996R/SG92R servos)
    - Document brain modules with descriptions
    - List known physical and software issues
    - Rename PyBullet brain files for clarity
    [RupertBrainPyBulletV1.py, RupertBrainPyBulletV2.py]
2026-05-08 feat: add Pico firmware and expand README
    - Add firmware/pico_servo_protected.py (MicroPython, runs on Pico 2)
    - Document architecture diagram (PC brain -> Pico -> servos)
    - Add firmware section with pin mapping and serial protocol
    - Flag PyBullet/RL scripts as partial 2-DOF assembly
    - Add Roadmap section (Isaac MCP, vision module, full RL env)
    - Expand Known Issues with software/simulation limitations
2026-05-08 refactor: rename firmware to peripheral_system.py, fix servo table
    - Rename pico_servo_protected.py -> peripheral_system.py
    - Fix servo mapping: shoulder is MG90S (not MG996R)
    - Hardware table now lists each servo by joint and pin number
    [peripheral_system.py]
2026-05-08 docs: note SG92R carbon fiber gears in servo table
2026-05-08 fix: correct Kitronik board URL
2026-05-08 docs: add kinematics section with joint chain and DOF description
2026-05-19 feat: add vision MCP, Isaac Sim MCP, bridge script, and Claude commands
    - src/mcp/RupertVisionMCP.py: webcam MCP server (rupert-vision) with frame
    capture, continuous monitoring, motion detection, and blue-mat-based
    Rupert detection with HSV calibration tools
    - src/mcp/IsaacUSDMCP.py: Isaac Sim MCP (isaac-usd) that connects to the
    bridge script via TCP to inspect and control the simulation
    - src/brain/IsaacBridgeScript.py: thread-safe TCP bridge for Isaac Sim —
    queues USD API calls onto Isaac's main loop to avoid race conditions
    - scripts/teste_visao_rupert.py: standalone real-time vision test with
    YOLO, ArUco, motion mask, and debug HSV panels
    - .claude/commands/: three project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
    [IsaacBridgeScript.py, IsaacUSDMCP.py, RupertVisionMCP.py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]
